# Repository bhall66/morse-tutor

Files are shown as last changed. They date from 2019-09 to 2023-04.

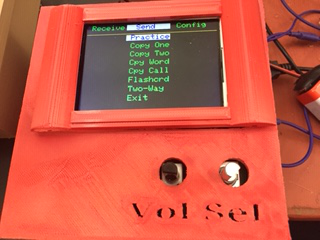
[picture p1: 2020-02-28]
Cases/N6API/Square/IMAGES/IMG_0469.JPG

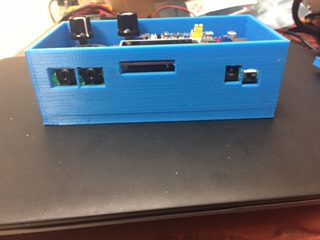
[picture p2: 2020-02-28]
Cases/N6API/Rectangle/IMAGES/IMG_0507.JPG

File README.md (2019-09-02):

# Morse-Tutor

An inexpensive device for learning Morse Code, using STM32F103C "Blue Pill" microcontroller board, 2.2" ILI9341 TFT, and rotary encoder.

Inspired by "Morse Code Tutor" by Jack Purdum W8TEE.

Full description and 8-part tutorial available at w8bh.net

Folders in this project: "MorseTutor" contains the latest source code. "Tutorials" contains sketches for the 8-part tutorial.  "Troubleshooting" has sketches for hardware validation (screen, encoder, etc).  "Book texts" contains ASCII text for a few classic books.  Put them on your SD card for code practice.

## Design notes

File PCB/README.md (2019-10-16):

This folder contains PCB gerbers for the Blue Pill version of the W8BH Morse Tutor

REVISION HISTORY ---
Rev 1: test version. 
Rev 2: initial public release. 
Rev 2A: enlarged holes for speaker pins.

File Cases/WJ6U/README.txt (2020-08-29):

These are the STL files to create a case for Bruce Hall's STM32(Blue Pill) Morse Code Tutor  with a 2.2" TFT Display with access to the SD slot. There is one case bottom with two top styles. These files were created with FreeCad. 

The CaseTopStyle1.stl is for builds with the MCU mounted on headers. The CaseTopStyle2.stl is 
for the builds with the MCU soldered to the board.   

There are photos in the IMAGE directory.

Rocco, WJ6U.

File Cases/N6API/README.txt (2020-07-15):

This release are the necessary files to create a case for Bruce Hall's Morse Code Tutors.  There are 2 cases in this release.  

The Folder Square contains all the Objects created from TinkerCad for the case for the ESP32 based PCB with a 3.2" TFT Display with access to the SD slot.

The Folder Rectangle contains all the Objects created from TinkerCad for the case for the STM32(Blue Pill) based PCB with a 2.2" TFT Display with access to the SD slot.

The directory named IMAGES has photos of the square case for reference.

John, NPAPI.

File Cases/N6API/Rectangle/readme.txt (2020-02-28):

This is the README file for the MCT Case for the Rectangular PCB.  It is designed for the 2.2 inch TFT display with SD socket.  The Case has access holes for all Jacks in the back of the Case. I am designing the rectangular case for larger displays.  Those will be released as soon as they are finalized. 

The bezel that goes along with the case is designed to be glued into place but is not required.  It does cover the edges of the TFT and fits well on the case.  There are two different bezels for your use.  Maybe you want to print your own bezel - That is great also.

The case was designed with TinkerCad and Sliced with Cura.  I used all defaults of Cura to Slice the parts of the case.  It was printed using a Creality Ender-3 Pro.  No Special settings in Cura.  Infill was set to 20%,  No Supports are needed.

Have Fun!  If you have any questions - Feel free to email me at johnbahun@gmail.com

Best of Luck

73 - John - N6API

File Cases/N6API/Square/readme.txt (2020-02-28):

This is the README file for the MCT Case for the Square PCB.  It is designed for the 3.2 inch TFT display with SD socket.  The Case has access holes for all Jacks in the back of the Case.  It also has a hole on the side for access to the USB connection to the ESP32.  With careful use of a screwdriver, the two push buttons on the ESP32 can also be accessed.

The bezel that goes along with the case is designed to be glued into place but is not required.  It does cover the edges of the TFT and fits well on the case.

The case was designed with TinkerCad and Sliced with Cura.  I used all defaults of Cura to Slice the parts of the case.  It was printed using a Creality Ender-3 Pro.  No Special settings in Cura.  Infill was set to 20%,  No Supports are needed.

Have Fun!  If you have any questions - Feel free to email me at johnbahun@gmail.com

Best of Luck

73 - John - N6API

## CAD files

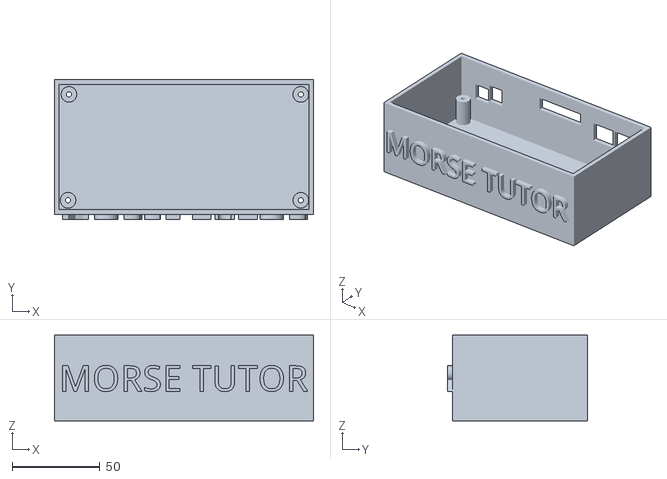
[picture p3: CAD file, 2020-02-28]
Cases/N6API/Rectangle/W8BH Case Bottom Long PCB.stl
148.0 x 80.0 x 49.0

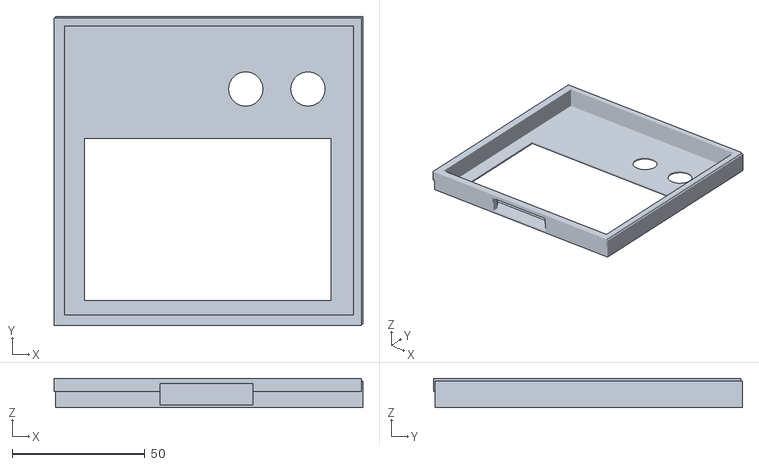
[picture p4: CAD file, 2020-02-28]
Cases/N6API/Square/W8BH Case Top Square.stl
116.5 x 116.5 x 11.0

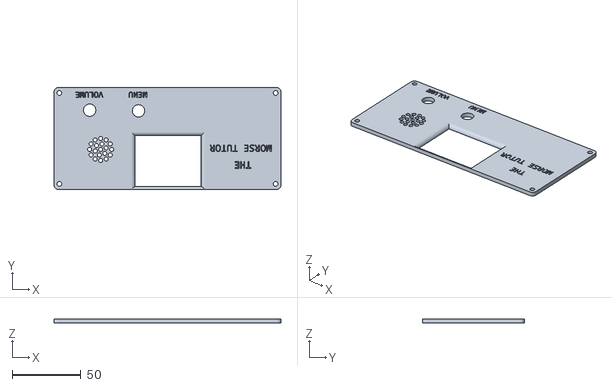
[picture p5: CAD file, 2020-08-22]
Cases/WJ6U/CaseTopStyle2.stl
164.8 x 73.9 x 3.00

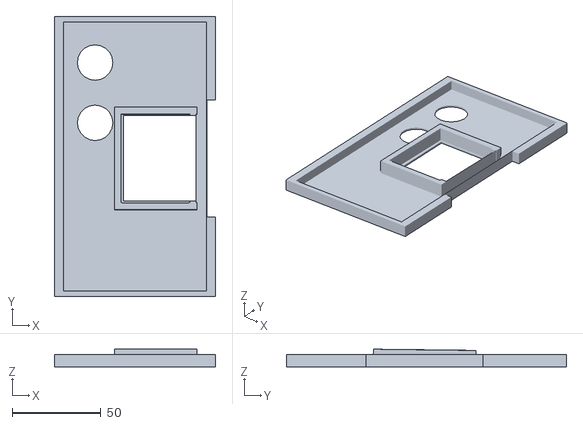
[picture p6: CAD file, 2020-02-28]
Cases/N6API/Rectangle/W8BH Case Top Long PCB.stl
91.0 x 158.0 x 10.0

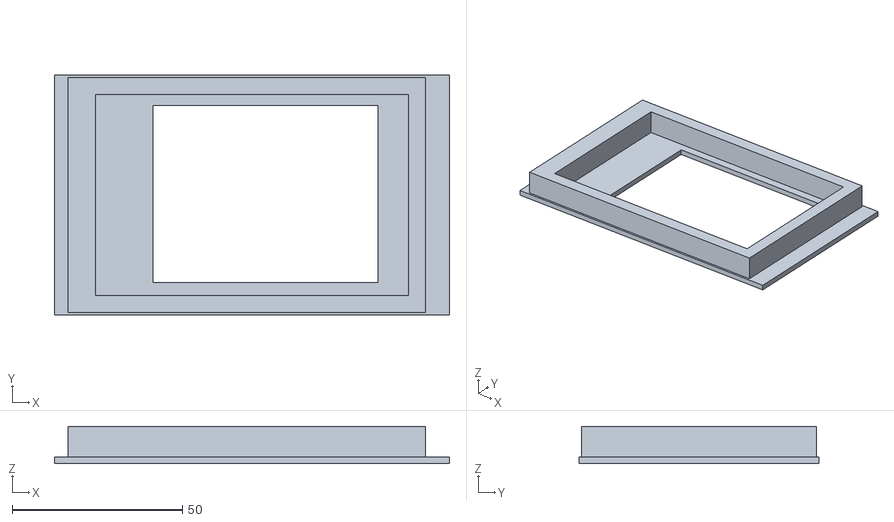
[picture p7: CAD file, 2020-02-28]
Cases/N6API/Square/W8BH Display Bezel Square.stl
116.0 x 70.5 x 11.0

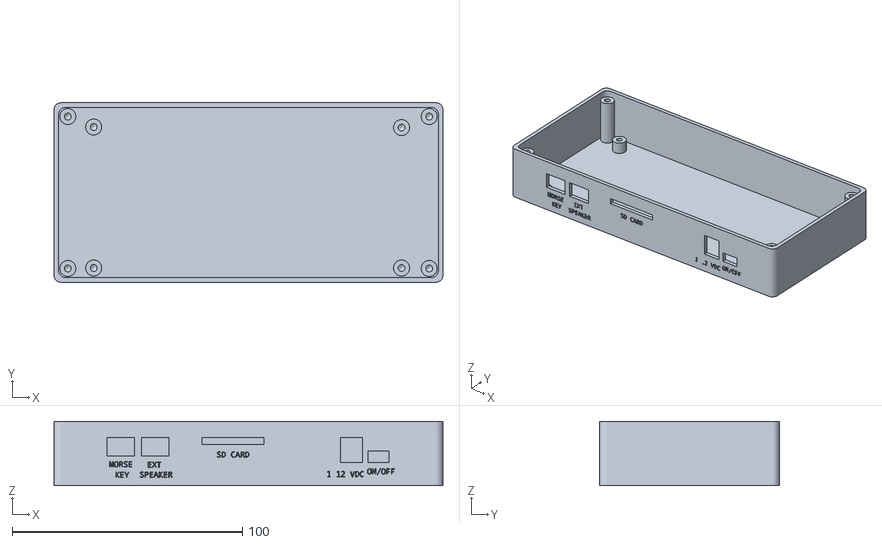
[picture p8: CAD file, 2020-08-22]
Cases/WJ6U/CaseBottom.stl
169.0 x 78.0 x 28.0

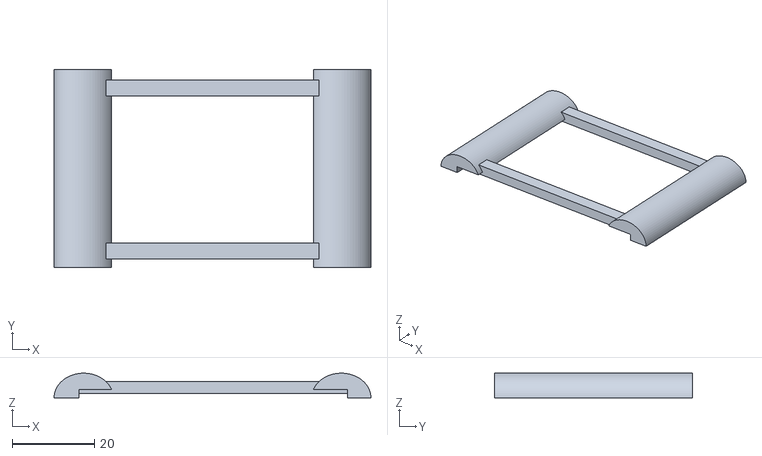
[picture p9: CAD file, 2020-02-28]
Cases/N6API/Rectangle/W8BH Display Round Bezel Long PCB.stl
77.0 x 48.0 x 6.00

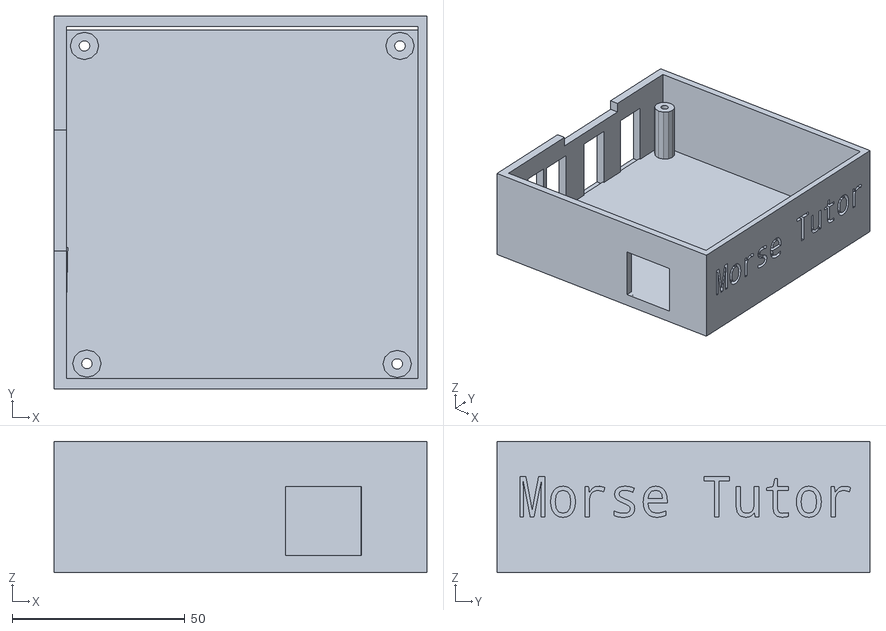
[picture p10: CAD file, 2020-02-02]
Cases/N6API/Square/W8BH Case Bottom Square.stl
108.0 x 108.0 x 38.0

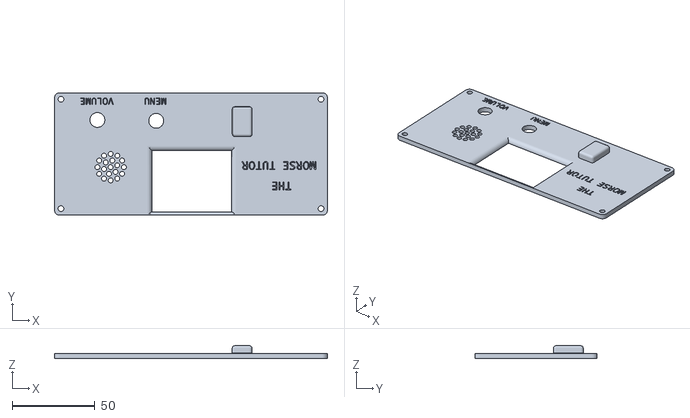
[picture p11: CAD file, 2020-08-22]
Cases/WJ6U/CaseTopStyle1.stl
164.8 x 73.9 x 7.60

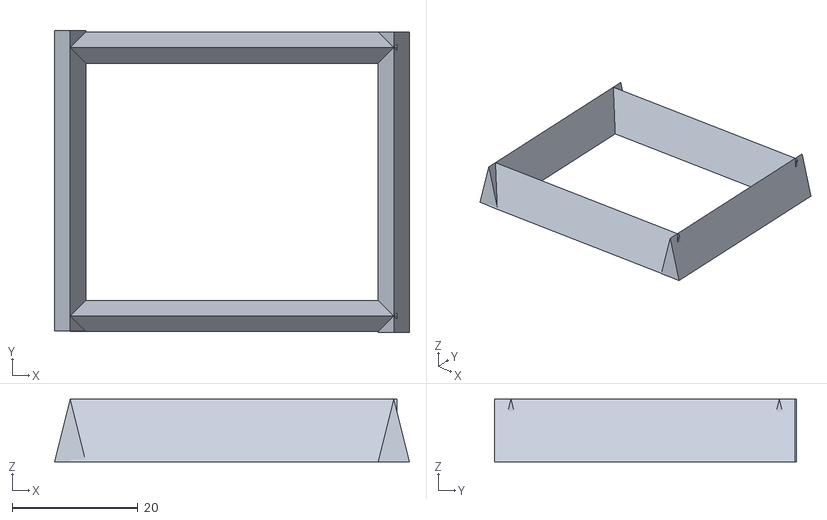
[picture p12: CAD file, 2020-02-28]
Cases/N6API/Rectangle/W8BH Display Angled Bezel Long PCB.stl
56.5 x 48.0 x 10.0

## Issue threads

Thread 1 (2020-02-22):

SD card not working?

wurzelmuschel, 2020-02-22:
Hi,

if I insert an SD card into the Morse Tutor and click on "Receive -> SD Card", the file selector menu shows only gibberish. I formatted the SD card with a FAT file system and added a file with only five characters and a .txt extension, so there should not be any problem.

Interestingly enough it does not make a difference whether I insert an SD card into the card reader or not, the menu always shows a lot of "random noise" filenames, so I guess there is something broken with the SD Card library from the STM32 Arduino core.

I am using the latest Arduino IDE (1.8.10) with up-to-date libraries. Can someone verify this strange behavior?

Thanks,
Christoph

bhall66, 2020-03-04:
Christoph,
Have you tried using one of the text files I supply with the code?

Bruce
w8bh.net

wurzelmuschel, 2020-03-05:
Bruce,

I just downloaded the files from the git repository onto a newly formatted SD card, and (of course) this time it worked. I don't know what exactly happened the last time I tried it, but two devices built by two OMs were not able to play back the files I downloaded, while they were readable on my PC.

Anyway, thanks again and sorry for bothering you. All is well that ends well ;-)

Cheers,
Christoph

Closed 2020-03-05.

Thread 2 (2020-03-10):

Minor code issue for rotary_counter/RotaryCounter

wwoofbum, 2020-03-10:
Hiya!  Working through your excellent tutorial.  Currently working on the rotary encoder section.  In the comments section for the rotary encoder section of MorseTutor.ino, as listed on github, you note that "The rotary 'position' is held in rotary_counter..."   In the following code, the variable is coded as "rotaryCounter."

Additionally, when I attempt to compile the application as coded in your tutorial Part 5, the Arduino IDE reports that "rotary_counter" is not defined.

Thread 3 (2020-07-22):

New Version Compile Problem

jettetsoi, 2020-07-22:
Thank you very much for the project. It is really cool.  I have the ESP32 version. I am now trying  to use the blue_pill one but there are some problems:

C:\Users\***\Desktop\Arduino\morse-tutor-master\MorseTutor\MorseTutor.ino: In function 'void initBacklight(int)':
MorseTutor:1809:3: error: 'timer' was not declared in this scope
   timer.setPrescaleFactor(1);                     // do not scale 72MHz sys clock
   ^
Multiple libraries were found for "Wire.h"
 Used: C:\Users\***\AppData\Local\Arduino15\packages\stm32duino\hardware\STM32F1\2020.6.20\libraries\Wire
 Not used: C:\Users\***AppData\Local\Arduino15\packages\stm32duino\hardware\STM32F1\2020.6.20\libraries\WireSlave
Multiple libraries were found for "Adafruit_ILI9341.h"
 Used: C:\Users\***\Documents\Arduino\libraries\Adafruit_ILI9341
 Not used: C:\Users\\***\AppData\Local\Arduino15\packages\stm32duino\hardware\STM32F1\2020.6.20\libraries\Adafruit_ILI9341
exit status 1
'timer' was not declared in this scope

There is no problem in the old version. I have already installed stm32 support from dan.drown.org.

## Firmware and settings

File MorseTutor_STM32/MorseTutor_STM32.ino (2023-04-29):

/**************************************************************************
       Title:   Morse Tutor
      Author:   Bruce E. Hall, w8bh.net
        Date:   28 Apr 2023
    Hardware:   STM32F103C, ILI9341 TFT display
    Software:   Arduino IDE 1.8.19; STM32 support via stm32duino
       Legal:   Copyright (c) 2023  Bruce E. Hall.
                Open Source under the terms of the MIT License. 
    
 Description:   Practice sending & receiving morse code
                Inspired by Jack Purdum's "Morse Code Tutor"
                
                THIS VERSION USING OFFICIAL STM32 CORE v2.5.0 at
                https://github.com/stm32duino/Arduino_Core_STM32

                Comment out the FAKE_CHIP define if you are using
                a genuine STMicroelectronics MCU

 **************************************************************************/

#define FAKE_CHIP                                 // using fake STM32F103C8 MCU

//===================================  INCLUDES ========================================= 
#include "Adafruit_GFX.h"                         // version 1.11.5
#include "Adafruit_ILI9341.h"                     // version 1.5.12
#ifdef FAKE_CHIP
  #include "FlashStorage_STM32F1.h"               // version 1.1.0
#else
  #include "EEPROM.h"                             // built-in library
#endif
#include "SD.h"                                   // version 1.2.4

//===================================  Hardware Connections =============================
#define TFT_DC            D20                     // Display "DC" pin on PA0
#define TFT_CS            D21                     // Display "CS" pin on PA1
#define TFT_MOSI          PA7                     // Display "MOSI" pin
#define TFT_SCK           PA5                     // Display "SCK" pin    
#define SD_CS             PA4                     // SD card "CS" pin
#define SD_MISO           PA6                     // SD card "MISO" pin
#define ENCODER_A         PA9                     // Rotary Encoder output A
#define ENCODER_B         PA8                     // Rotary Encoder output B
#define ENCODER_BUTTON    PB15                    // Rotary Encoder switch
#define PADDLE_A          PB8                     // Morse Paddle "dit"
#define PADDLE_B          PB7                     // Morse Paddle "dah"
#define AUDIO             PA2                     // Audio output
#define BACKLIGHT         PB1                     // Display Backlight control
#define LED               PC13                    // onboard LED pin
#define SCREEN_ROTATION     3                     // landscape mode: use '1' or '3'
#define PNP_DRIVER        true                    // true = using PNP to drive backlight

//===================================  Morse Code Constants =============================
#define DEFAULTSPEED       13                     // character speed in Words per Minute
#define MAXSPEED           50                     // fastest morse speed in WPM
#define MINSPEED            3                     // slowest morse speed in WPM
#define DEFAULTPITCH     1200                     // default pitch in Hz of morse audio
#define MAXPITCH         2800                     // highest allowed pitch
#define MINPITCH          300                     // how low can you go
#define WORDSIZE            5                     // number of chars per random word
#define MAXWORDSPACES      99                     // maximum word delay, in spaces
#define FLASHCARDDELAY   2000                     // wait in mS between cards
#define ENCODER_TICKS       3                     // Ticks required to register movement
#define FNAMESIZE          15                     // max size of a filename
#define MAXFILES           20                     // max number of SD files recognized
#define IAMBIC_A            1                     // Iambic Keyer Mode B 
#define IAMBIC_B            2                     // Iambic Keyer Mode A
#define LONGPRESS        1000                     // hold-down time for long press, in mSec
#define SUPPRESSLED     false                     // if true, do not flash diagnostic LED

//===================================  Color Constants ==================================
#define BLACK          0x0000
#define BLUE           0x001F
#define NAVY           0x000F               
#define RED            0xF800
#define MAROON         0x7800 
#define GREEN          0x07E0
#define LIME           0x0400
#define CYAN           0x07FF
#define TEAL           0x03EF
#define PURPLE         0x780F                
#define PINK           0xF81F
#define YELLOW         0xFFE0
#define ORANGE         0xFD20
#define BROWN          0x79E0
#define WHITE          0xFFFF
#define OLIVE          0x7BE0
#define SILVER         0xC618        
#define GRAY           0x7BEF
#define DARKGRAY       0x1208

const word colors[] = {BLACK,BLUE,NAVY,RED,MAROON,GREEN,LIME,CYAN,TEAL,PURPLE,
  PINK,YELLOW,ORANGE,BROWN,WHITE,OLIVE,SILVER,GRAY,DARKGRAY};

// ==================================  Menu Constants ===================================
#define DISPLAYWIDTH      320                     // Number of LCD pixels in long-axis
#define DISPLAYHEIGHT     240                     // Number of LCD pixels in short-axis
#define TOPMARGIN          30                     // All submenus appear below top line
#define MENUSPACING       100                     // Width in pixels for each menu column
#define ROWSPACING         23                     // Height in pixels for each text row
#define COLSPACING         12                     // Width in pixels for each text character
#define MAXCOL   DISPLAYWIDTH/COLSPACING          // Number of characters per row    
#define MAXROW  (DISPLAYHEIGHT-TOPMARGIN)/ROWSPACING  // Number of text-rows per screen
#define FG              GREEN                     // Menu foreground color 
#define BG              BLACK                     // App background color
#define SELECTFG         BLUE                     // Selected Menu foreground color
#define SELECTBG        WHITE                     // Selected Menu background color
#define TEXTCOLOR      YELLOW                     // Default non-menu text color
#define ELEMENTS(x) (sizeof(x) / sizeof(x[0]))    // Handy macro for determining array sizes

Adafruit_ILI9341 tft = Adafruit_ILI9341(TFT_CS, TFT_DC);
HardwareTimer *timer = new HardwareTimer(TIM1);   // Need timer3 access for backlight PWM

//===================================  Rotary Encoder Variables =========================
volatile int      rotaryCounter    = 0;           // "position" of rotary encoder (increments CW) 
volatile boolean  button_pressed   = false;       // true if the button has been pushed
volatile boolean  button_released  = false;       // true if the button has been released (sets button_downtime)
volatile long     button_downtime  = 0L;          // ms the button was pushed before released

//===================================  Morse Code Variables =============================

                    // The following is a list of the 100 most-common English words, in frequency order.
                    // See: https://www.dictionary.com/e/common-words/
                    // from The Brown Corpus Standard Sample of Present-Day American English 
                    // (Providence, RI: Brown University Press, 1979)
                    
char *words[]     = {"THE", "OF", "AND", "TO", "A", "IN", "THAT", "IS", "WAS", "HE", 
                     "FOR", "IT", "WITH", "AS", "HIS", "ON", "BE", "AT", "BY", "I", 
                     "THIS", "HAD", "NOT", "ARE", "BUT", "FROM", "OR", "HAVE", "AN", "THEY", 
                     "WHICH", "ONE", "YOU", "WERE", "ALL", "HER", "SHE", "THERE", "WOULD", "THEIR", 
                     "WE", "HIM", "BEEN", "HAS", "WHEN", "WHO", "WILL", "NO", "MORE", "IF", 
                     "OUT", "SO", "UP", "SAID", "WHAT", "ITS", "ABOUT", "THAN", "INTO", "THEM", 
                     "CAN", "ONLY", "OTHER", "TIME", "NEW", "SOME", "COULD", "THESE", "TWO", "MAY", 
                     "FIRST", "THEN", "DO", "ANY", "LIKE", "MY", "NOW", "OVER", "SUCH", "OUR", 
                     "MAN", "ME", "EVEN", "MOST", "MADE", "AFTER", "ALSO", "DID", "MANY", "OFF", 
                     "BEFORE", "MUST", "WELL", "BACK", "THROUGH", "YEARS", "MUCH", "WHERE", "YOUR", "WAY"  
                    };
char *antenna[]   = {"YAGI", "DIPOLE", "VERTICAL", "HEXBEAM", "MAGLOOP"};
char *weather[]   = {"HOT", "SUNNY", "WARM", "CLOUDY", "RAINY", "COLD", "SNOWY", "CHILLY", "WINDY", "FOGGY"};
char *names[]     = {"WAYNE", "TYE", "DARREN", "MICHAEL", "SARAH", "DOUG", "FERNANDO", "CHARLIE", "HOLLY",
                     "KEN", "SCOTT", "DAN", "ERVIN", "GENE", "PAUL", "VINCENT"};
char *cities[]    = {"DAYTON, OH", "HADDONFIELD, NJ", "MURRYSVILLE, PA", "BALTIMORE, MD", "ANN ARBOR, MI", 
                     "BOULDER, CO", "BILLINGS, MT", "SANIBEL, FL", "CIMMARON, NM", "TYLER, TX", "OLYMPIA, WA"};
char *rigs[]      = {"YAESU FT101", "KENWOOD 780", "ELECRAFT K3", "HOMEBREW", "QRPLABS QCX", "ICOM 7410", "FLEX 6400"};
char punctuation[]= "!@$&()-+=,.:;'/";
char prefix[]     = {'A', 'W', 'K', 'N'};
char koch[]       = "KMRSUAPTLOWI.NJEF0Y,VG5/Q9ZH38B?427CLD6X";
byte morse[] = {                                  // Each character is encoded into an 8-bit byte:
  0b01001010,        // ! exclamation        
  0b01101101,        // " quotation          
  0b01010111,        // # pound                   // No Morse, mapped to SK
  0b10110111,        // $ dollar or ~SX
  0b00000000,        // % percent
  0b00111101,        // & ampersand or ~AS
  0b01100001,        // ' apostrophe
  0b00110010,        // ( open paren
  0b01010010,        // ) close paren
  0b0,               // * asterisk                // No Morse
  0b00110101,        // + plus or ~AR
  0b01001100,        // , comma
  0b01011110,        // - hypen
  0b01010101,        // . period
  0b00110110,        // / slant   
  0b00100000,        // 0                         // Read the bits from RIGHT to left,   
  0b00100001,        // 1                         // with a "1"=dit and "0"=dah
  0b00100011,        // 2                         // example: 2 = 11000 or dit-dit-dah-dah-dah
  0b00100111,        // 3                         // the final bit is always 1 = stop bit.
  0b00101111,        // 4                         // see "sendElements" routine for more info.
  0b00111111,        // 5
  0b00111110,        // 6
  0b00111100,        // 7
  0b00111000,        // 8
  0b00110000,        // 9
  0b01111000,        // : colon
  0b01101010,        // ; semicolon
  0b0,               // <                         // No Morse
  0b00101110,        // = equals or ~BT
  0b0,               // >                         // No Morse
  0b01110011,        // ? question
  0b01101001,        // @ at or ~AC
  0b00000101,        // A 
  0b00011110,        // B
  0b00011010,        // C
  0b00001110,        // D
  0b00000011,        // E
  0b00011011,        // F
  0b00001100,        // G
  0b00011111,        // H
  0b00000111,        // I
  0b00010001,        // J
  0b00001010,        // K
  0b00011101,        // L
  0b00000100,        // M
  0b00000110,        // N
  0b00001000,        // O
  0b00011001,        // P
  0b00010100,        // Q
  0b00001101,        // R
  0b00001111,        // S
  0b00000010,        // T
  0b00001011,        // U
  0b00010111,        // V
  0b00001001,        // W
  0b00010110,        // X
  0b00010010,        // Y 
  0b00011100         // Z
};

int charSpeed   = DEFAULTSPEED;                   // speed at which characters are sent, in WPM
int codeSpeed   = DEFAULTSPEED;                   // overall code speed, in WPM
int ditPeriod   = 100;                            // length of a dit, in milliseconds
int ditPaddle   = PADDLE_A;                       // digital pin attached to dit paddle
int dahPaddle   = PADDLE_B;                       // digital pin attached to dah paddle
int pitch       = DEFAULTPITCH;                   // frequency of audio output, in Hz
int kochLevel   = 1;                              // current Koch lesson #
int score       = 0;                              // copy challange score
int hits        = 0;                              // copy challange correct #
int misses      = 0;                              // copy channange incorrect #
int xWordSpaces = 0;                              // extra spaces between words
int keyerMode   = IAMBIC_B;                       // current keyer mode
bool usePaddles = false;                          // if true, using paddles; if false, straight key
bool paused     = false;                          // if true, morse output is paused
bool ditRequest = false;                          // dit memory for iambic sending
bool dahRequest = false;                          // dah memory for iambic sending
bool inStartup  = true;                           // startup flag
char myCall[10] = "W8BH";
int textColor   = TEXTCOLOR;                      // foreground (text) color
int bgColor     = BG;                             // background (screen) color
int brightness  = 100;                            // backlight level (range 0-100%)
int startItem   = -1;                             // startup activity.  -1 = main menu


//===================================  Menu Variables ===================================
int  menuCol=0, textRow=0, textCol=0;
char *mainMenu[] = {" Receive ", "  Send  ", "Config "};        
char *menu0[]    = {" Koch    ", " Letters ", " Words   ", " Numbers ", " Mixed   ", " SD Card ", " QSO     ", " Callsign", " Exit    "};
char *menu1[]    = {" Practice", " Copy One", " Copy Two", " Cpy Word", " Cpy Call", " Flashcrd", " Head Cpy", " Two-Way ", " Exit    "};
char *menu2[]    = {" Speed   ", " Chk Spd ", " Tone    ", " Key     ", " Callsign", " Screen  ", " Defaults", " Exit    "};


//===================================  Rotary Encoder Code  =============================

/* 
   Rotary Encoder Button Interrupt Service Routine ----------
   Process encoder button presses and releases, including debouncing (extra "presses" from 
   noisy switch contacts). If button is pressed, the button_pressed flag is set to true. If 
   button is released, the button_released flag is set to true, and button_downtime will 
   contain the duration of the button press in ms.  Manually reset flags after handling event. 
*/

void buttonISR()
{  
  static boolean button_state = false;
  static unsigned long start, end;  
  boolean pinState = digitalRead(ENCODER_BUTTON);
  
  if ((pinState==LOW) && (button_state==false))                     
  {                                               // Button was up, but is now down
    start = millis();                             // mark time of button down
    if (start > (end + 10))                       // was button up for 10mS?
    {
      button_state = true;                        // yes, so change state
      button_pressed = true;
    }
  }
  else if ((pinState==HIGH) && (button_state==true))                       
  {                                               // Button was down, but now up
    end = millis();                               // mark time of release
    if (end > (start + 10))                       // was button down for 10mS?
    {
      button_state = false;                       // yes, so change state
      button_released = true;
      button_downtime = end - start;              // and record how long button was down
    }
  }
}

/* 
   Rotary Encoder Interrupt Service Routine ---------------
   This is an alternative to rotaryISR() above.
   It gives twice the resolution at a cost of using an additional interrupt line
   This function will runs when either encoder pin A or B changes state.
   The states array maps each transition 0000..1111 into CW/CCW rotation (or invalid).
   The rotary "position" is held in rotary_counter, increasing for CW rotation, decreasing 
   for CCW rotation. If the position changes, rotary_change will be set true. 
   You should set this to false after handling the change.
   To implement, attachInterrupts to encoder pin A *and* pin B 
*/

void rotaryISR()
{
  const int states[] = {0,1,-1,0,-1,0,0,1,1,0,0,-1,0,-1,1,0};
  static byte transition = 0;                     // holds current and previous encoder states   
  transition <<= 2;                               // shift previous state up 2 bits
  transition |= (digitalRead(ENCODER_A));         // put encoder_A on bit 0
  transition |= (digitalRead(ENCODER_B) << 1);    // put encoder_B on bit 1
  transition &= 0x0F;                             // zero upper 4 bits
  rotaryCounter += states[transition];            // update counter +/- 1 based on rotation
}

boolean buttonDown()                              // check CURRENT state of button
{
  return (digitalRead(ENCODER_BUTTON)==LOW);
}

void waitForButtonRelease()
{
  if (buttonDown())                               // make sure button is currently pressed.
  {
    button_released = false;                      // reset flag
    while (!button_released) ;                    // and wait for release                     
  }
}

void waitForButtonPress()
{
  if (!buttonDown())                              // make sure button is not pressed.
  {
    while (!button_pressed) ;                     // wait for press
    button_pressed = false;                       // and reset flag
  }  
}

bool longPress()
{
  waitForButtonRelease();                         // wait until button is released
  return (button_downtime > LONGPRESS);           // then check time is was held down
}

/* 
   readEncoder() returns 0 if no significant encoder movement since last call,
   +1 if clockwise rotation, and -1 for counter-clockwise rotation
*/

int readEncoder(int numTicks = ENCODER_TICKS) 
{
  static int prevCounter = 0;                     // holds last encoder position
  int change = rotaryCounter - prevCounter;       // how many ticks since last call?
  if (abs(change)<=numTicks)                      // not enough ticks?
    return 0;                                     // so exit with a 0.
  prevCounter = rotaryCounter;                    // enough clicks, so save current counter values
  return (change>0) ? 1:-1;                       // return +1 for CW rotation, -1 for CCW   
}


//===================================  Morse Routines ===================================

void keyUp()                                      // device-dependent actions 
{                                                 // when key is up:
  digitalWrite(LED,1);                            // turn off LED
  noTone(AUDIO);                                  // and turn off sound
}

void keyDown()                                    // device-dependent actions
{                                                 // when key is down:
  if (!SUPPRESSLED) digitalWrite(LED,0);          // turn on LED
  tone(AUDIO,pitch);                              // and turn on sound
}

bool ditPressed()
{
  return (digitalRead(ditPaddle)==0);             // pin is active low
}

bool dahPressed()
{
  return (digitalRead(dahPaddle)==0);             // pin is active low
}

int extracharDit()
{
  return (3158/codeSpeed) - (1958/charSpeed); 
}

int intracharDit()
{
  return (1200/charSpeed);
}

void characterSpace()
{
  int fudge = (charSpeed/codeSpeed)-1;            // number of fast dits needed to convert
  delay(fudge*ditPeriod);                         // single intrachar dit to slower extrachar dit
  delay(2*extracharDit());                        // 3 total (last element includes 1)                                
}

void wordSpace()
{
  delay(4*extracharDit());                        // 7 total (last char includes 3)
  if (xWordSpaces)                                // any user-specified delays?
    delay(7*extracharDit()*xWordSpaces);          // yes, so additional wait between words
}
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
void loop()
{
  int selection = startItem;                      // start with user specified startup screen
  if (!inStartup || (startItem<0))                // but, if there isn't one,                 
    selection = getMenuSelection();               // get menu selection from user instead
  inStartup = false;                              // reset startup flag
  showSelection(selection);                       // display users selection at top of screen
  newScreen();                                    // and clear the screen below it.
  button_pressed = false;                         // reset flag for new presses
  randomSeed(millis());                           // randomize!
  score=0; hits=0; misses=0;                      // restart score for copy challenges  
  switch(selection)                               // do action requested by user
  {
    case 00: sendKoch(); break;
    case 01: sendLetters(); break;
    case 02: sendWords(); break;
    case 03: sendNumbers(); break;
    case 04: sendMixedChars(); break;
    case 05: sendFromSD(); break;
    case 06: sendQSO(); break;
    case 07: sendCallsigns(); break;

    case 10: practice(); break;
    case 11: copyOneChar(); break;
    case 12: copyTwoChars(); break;
    case 13: copyWords(); break;
    case 14: copyCallsigns(); break;
    case 15: flashcards(); break;
    case 16: headCopy(); break;
    case 17: twoWay(); break;
    
    case 20: setSpeed(); break;
    case 21: checkSpeed(); break;
    case 22: setPitch(); break;
    case 23: configKey(); break;
    case 24: setCallsign(); break;
    case 25: setScreen(); break;
    case 26: useDefaults(); break;
    default: ;
  }  
}

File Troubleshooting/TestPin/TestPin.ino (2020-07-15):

/**************************************************************************
      Author:   Bruce E. Hall, w8bh.net
        Date:   07 Jul 2019
    Hardware:   STM32F103C "Blue Pill",
    Software:   Arduino IDE 1.8.9; stm32duino package @ dan.drown.org
    
 Description:   Test functionality of an individual pin.  To test:
                1) change TESTPIN define to the pin you want to test.
                2) upload the code.
                3) temporarily ground the test pin.
                4) onboard LED should flash while pin is grounded.
   
 **************************************************************************/

#define TESTPIN   PB7                // change to the pin you want to test!

#define LED       PC13               // DONT CHANGE THIS ONE

void setup() {
  pinMode(TESTPIN, INPUT_PULLUP);    // configure test Pin as input
  pinMode(LED, OUTPUT);              // configure onboard LED
  digitalWrite(LED, LOW);            // turn off LED
}

void flashLED() {
  digitalWrite(LED, HIGH);           // turn the LED on
  delay(200);                        // wait a bit 
  digitalWrite(LED, LOW);            // turn the LED off
  delay(200);                        // wait a bit

}

bool testPinIsGrounded()
{
  return !digitalRead(TESTPIN);
}

void loop() {
  if (testPinIsGrounded())           // if test pin is grounded...
    flashLED();                      // ...the LED will flash
}

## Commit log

2019-07-01 fixed small comment typ
    [MorseTutor_Part5.ino, MorseTutor_Part6.ino, MorseTutor_Part7.ino]
2019-07-12 updated pin assignments
2019-09-02 new pin assignments
2019-09-22 added pcb gerbers
    [MorseTutor1-B_Cu.gbr, MorseTutor1-B_Mask.gbr, MorseTutor1-B_Paste.gbr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]
2019-10-03 Enlarged PCB speaker holes
    [MorseTutor1-B_Cu.gbr, MorseTutor1-B_Mask.gbr, MorseTutor1-B_Paste.gbr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]
2019-10-06 added error checks for settings in EEPROM
    [MorseTutor.ino]
2019-10-09 Initial ESP32 code and PCB
    [MorseTutor1-B_Cu.gbr, MorseTutor1-B_Mask.gbr, MorseTutor1-B_Paste.gbr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]
2019-10-22 End-of-line fix for SD files
    [MorseTutor.ino]
2019-10-23 ESP32 catch-up; Head-copy break; Alt-scoring; Current key-mode displayed
2019-11-24 IDE 1.8.10, new placenames, improved esp32 file list
2019-12-01 ESP32 wireless fix
2019-12-09 ESP32 rev2B PCB
    [MorseTutor4-B_Cu.gbr, MorseTutor4-B_Mask.gbr, MorseTutor4-B_Paste.gbr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]
2019-12-15 fixed slow two-way receive; moved to official STM32 core
    [MorseTutor.ino, MorseTutor_ESP32.ino]
2020-02-02 added N6API Case files
    [W8BH Case Bottom Revision One.stl, W8BH Case Top Revision One.stl, W8BH Display Bezel Revision One.stl]
2020-02-28 N6API cases added
    [W8BH Case Bottom Long PCB.stl, W8BH Case Bottom Revision One.stl, W8BH Case Bottom Square.stl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]
2020-07-15 combined update
    New Features: user-selectable text color, new user-selectable background color, screen brightness control, user-selectable startup activity. Name of current activity is now displayed in the menu bar.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
2020-08-22 Added WJ6U case
    [CaseBottom.stl, CaseTopStyle1.stl, CaseTopStyle2.stl]
2020-08-29 Increased supported colors; ESP32 update
    For STM32 boards, added several additional colors for text and background. Improved how colors are stored in EEPROM.
    For ESP32, updated code to match STM32, adding a new menu item "config->screen" which allows user to select a startup activity and change the text/background colors
2020-09-09 fixed callsign on splash screen
    The user's callsign, which should appear on the startup screen, was accidentally removed in the previous version. Correct callsign display is restored in this version.
    [MorseTutor.ino, MorseTutor_ESP32.ino]
2022-01-07 updated software environment description
    The source code now indicates which board and library versions were used for compilation.
2022-05-12 fixed Koch Lesson 19
    [MorseTutor.ino, MorseTutor_ESP32.ino]
2023-04-27 Add STM32 folder
    This folder contains Morse Tutor source code and compiled code for the official STM32 Arduino core
2023-04-29 changed startup to main menu
    Previously, device would start with Koch activity. Main Menu startup seems to be a better default action.
2026-05-08 Update MorseTutor_ESP32.ino
    Fixed missing first character of SD-card filenames; Fixed esp32 v3 arduino board incompatibility due to ledc and ESP-NOW API changes.
    [MorseTutor_ESP32.ino]
